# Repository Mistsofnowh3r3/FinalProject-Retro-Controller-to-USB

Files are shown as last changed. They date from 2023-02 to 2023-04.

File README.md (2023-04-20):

# Retro  Nintendo Controller Adapter

> Arduino code, ccAdapterRemapper Solution, stl's and sldprt's for a case, and design and usage documentation

## Dependencies
- https://github.com/MHeironimus/ArduinoJoystickLibrary
- https://github.com/SukkoPera/N64PadForArduino
- https://github.com/arduino-libraries/Keyboard
- https://www.arduino.cc/en/software

## Stuff
-- Params.cs is a modification of the PARAMS code from https://github.com/redscientistlabs/RTCV

-- Overall visual design of ccAdapterRemapper is inspired by RTCV as well.

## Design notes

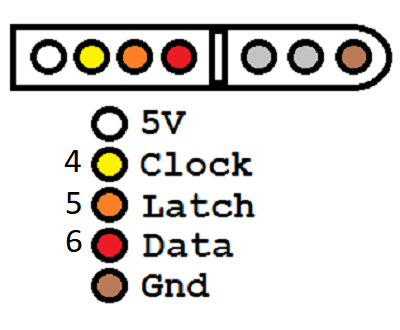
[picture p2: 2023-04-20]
Assets/Documentation/PINOUTS/SNES.png

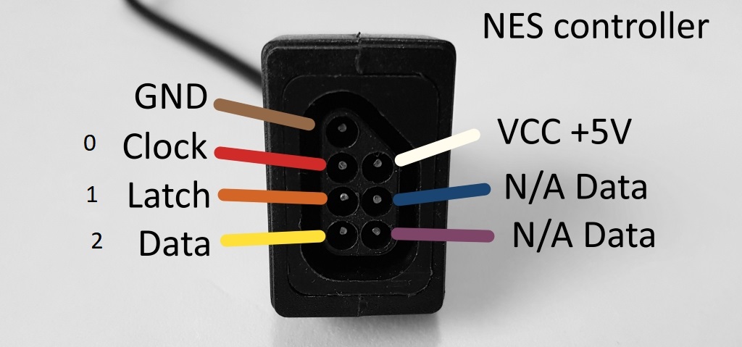
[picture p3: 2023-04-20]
Assets/Documentation/PINOUTS/NES.jpg

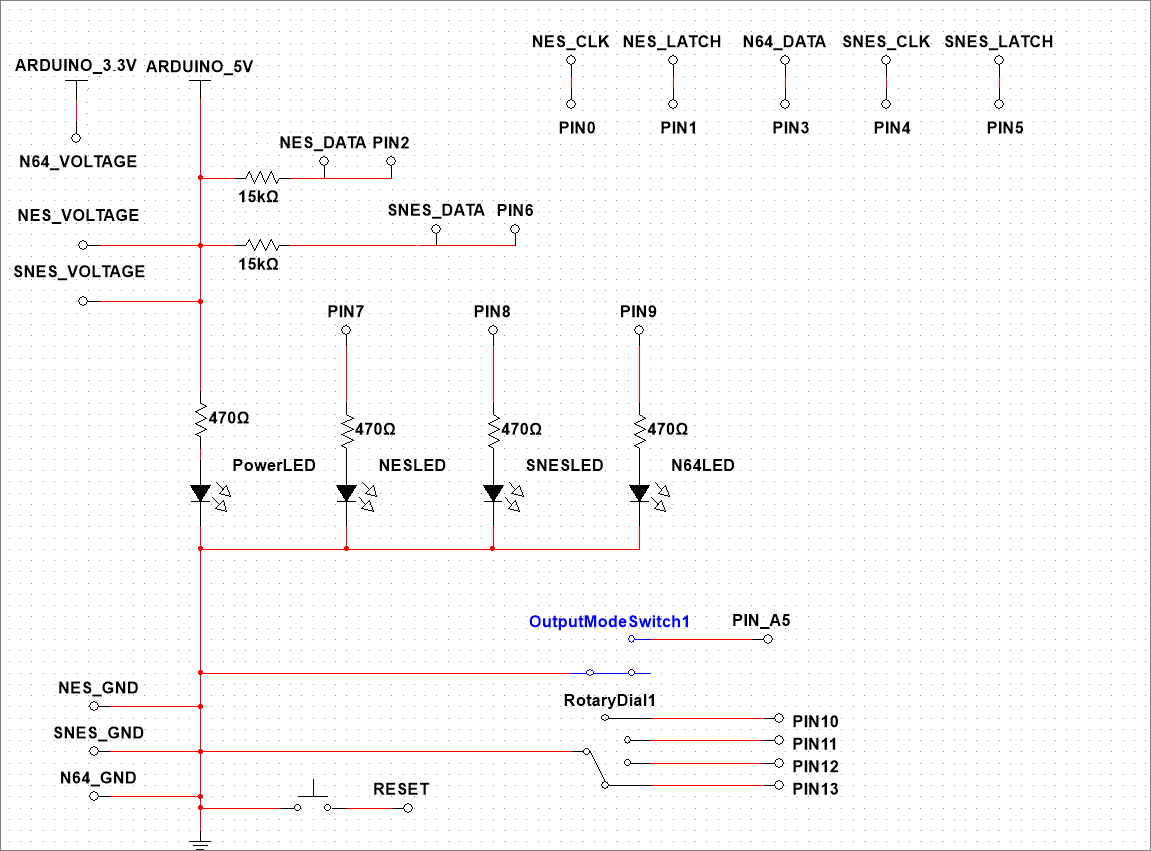
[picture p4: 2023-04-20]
Assets/Documentation/Circuit.png

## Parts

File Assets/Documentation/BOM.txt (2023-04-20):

4 LEDs
4 470 ohm or similar resistors for those LEDs
1 NES controller port
1 SNES controller port
1 N64 controller port
1 PBNO
1 SPDT switch
4 Position rotary dial
2 15k or similar pullup Resistors
1 Arduino Leonardo
1 Micro USB cable
Casing and wiring.

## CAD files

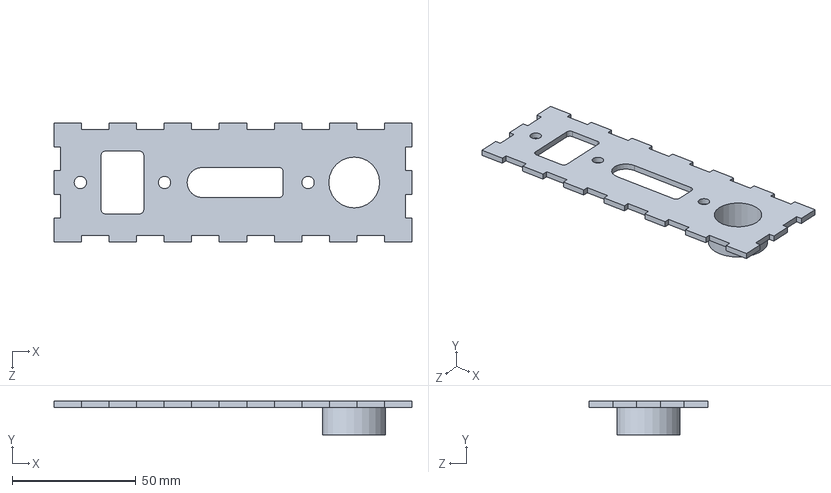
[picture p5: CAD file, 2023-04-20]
Assets/Case Model Files/Case Portside.SLDPRT
144.8 x 13.6 x 48.0 mm

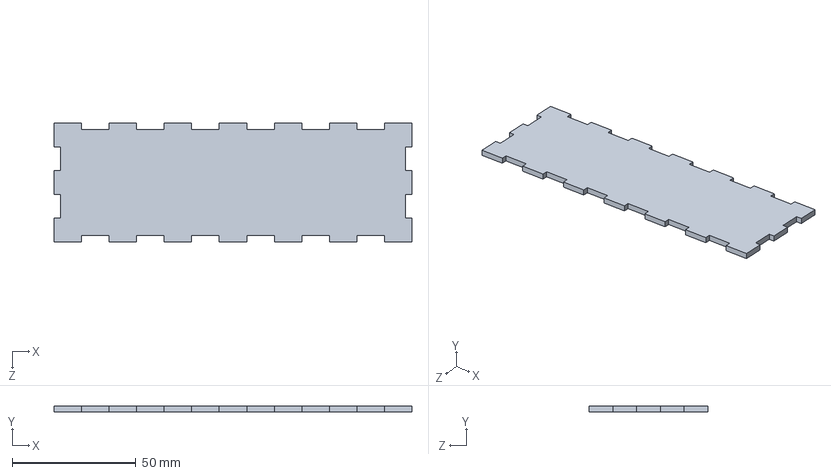
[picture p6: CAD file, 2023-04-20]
Assets/Case Model Files/Case Back Side.SLDPRT
144.8 x 2.54 x 48.0 mm

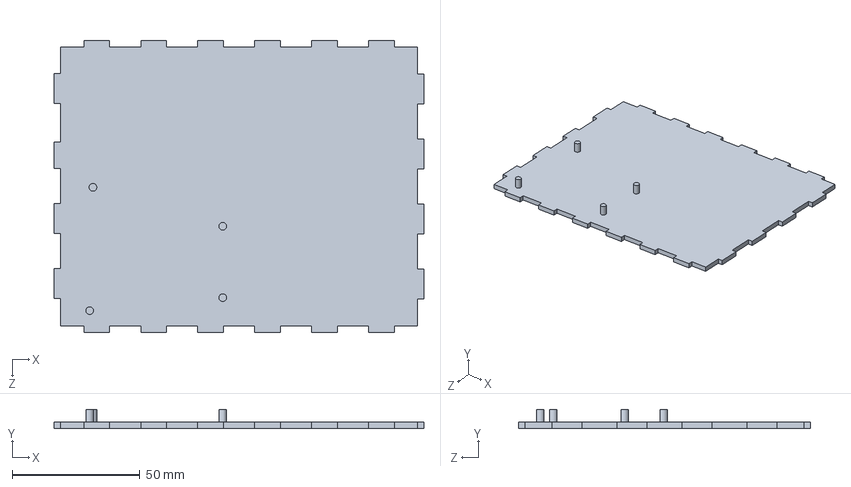
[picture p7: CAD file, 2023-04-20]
Assets/Case Model Files/Case Bottom.SLDPRT
144.8 x 7.62 x 114.3 mm

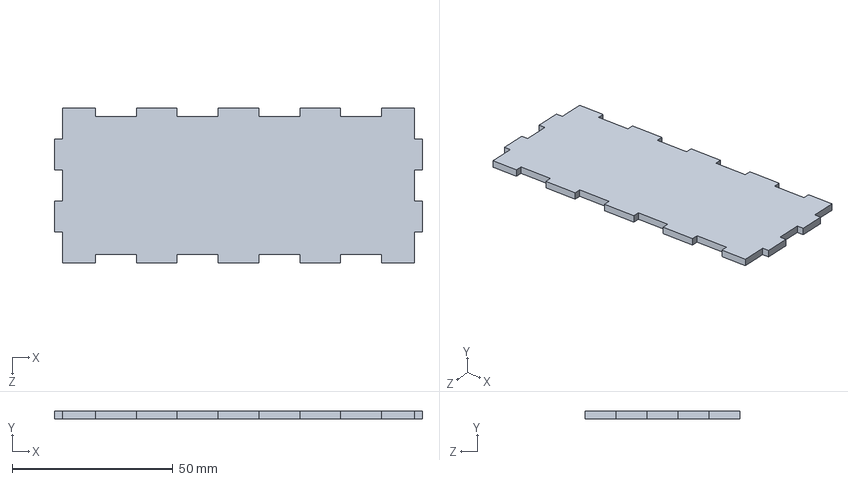
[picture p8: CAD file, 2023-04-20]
Assets/Case Model Files/Case Side.SLDPRT
114.3 x 2.54 x 48.0 mm

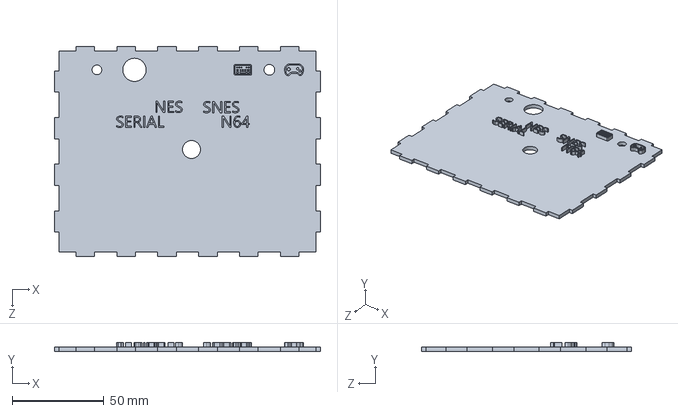
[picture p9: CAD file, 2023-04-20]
Assets/Case Model Files/Case Top.SLDPRT
144.8 x 5.08 x 114.3 mm

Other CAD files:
Assets/Case Model Files/Case Side Hole.SLDPRT
Assets/Case Model Files/Case Back Side.STL
Assets/Case Model Files/Case Bottom.STL
Assets/Case Model Files/Case Portside.STL
Assets/Case Model Files/Case Side Hole.STL
Assets/Case Model Files/Case Side.STL
Assets/Case Model Files/Case Top.STL

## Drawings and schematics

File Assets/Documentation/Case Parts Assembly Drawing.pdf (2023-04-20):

1

B B

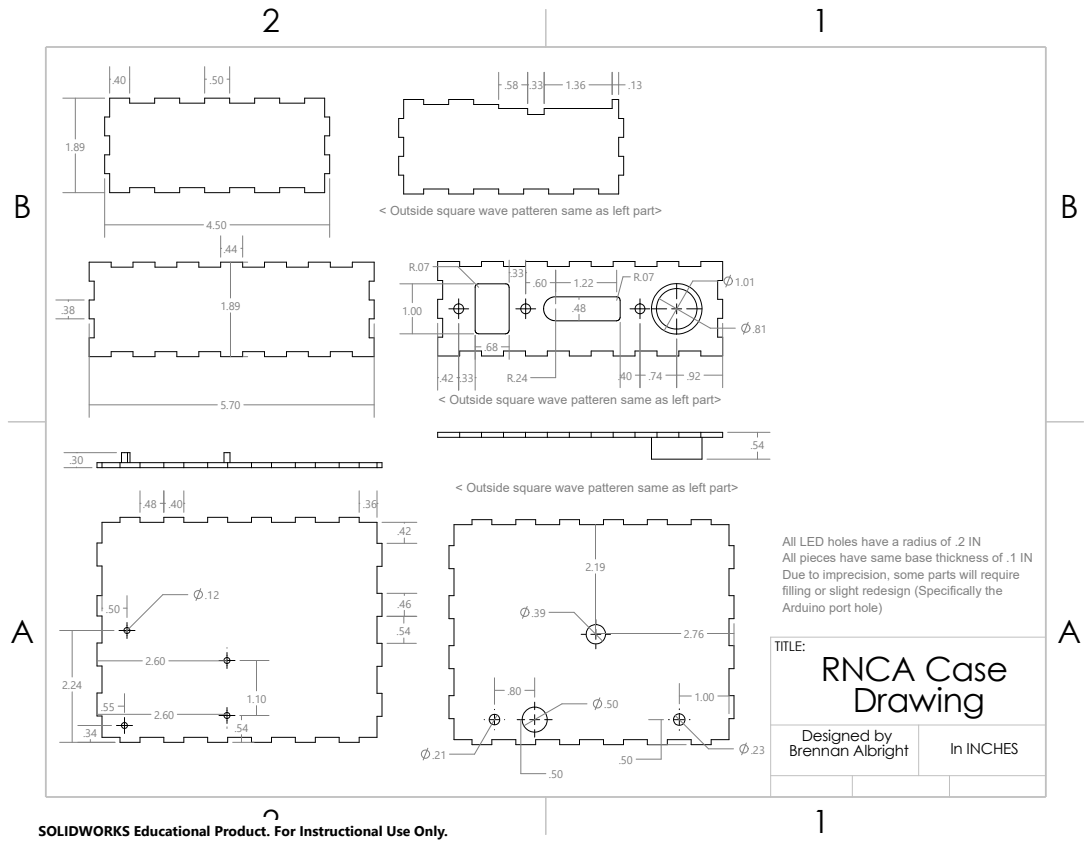
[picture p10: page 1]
TITLE:; Brennan Albright; Designed by; In INCHES

< Outside square wave patteren same as left part>

All LED holes have a radius of .2 IN
All pieces have same base thickness of .1 IN
Due to imprecision, some parts will require
filling or slight redesign (Specifically the
Arduino port hole)
RNCA Case
Drawing

SOLIDWORKS Educational Product. For Instructional Use Only.

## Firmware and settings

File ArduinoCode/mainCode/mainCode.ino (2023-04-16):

#include <N64Pad.h> // https://github.com/SukkoPera/N64PadForArduino
#include <Joystick.h> // https://github.com/MHeironimus/ArduinoJoystickLibrary
#include <Keyboard.h> // https://github.com/arduino-libraries/Keyboard
#include <EEPROM.h> // From Arduino IDE
#include <stdio.h> // From Arduino IDE

#pragma region // EEPROM MEMORY MAP
//0 NES A
//1 NES B
//2 NES SELECT
//3 NES START
//4 NES UP
//5 NES DOWN
//6 NES LEFT
//7 NES RIGHT
//8 SNES B
//9 SNES Y
//10 SNES UP
//11 SNES DOWN
//12 SNES LEFT
//13 SNES RIGHT
//14 SNES A 
//15 SNES X
//16 SNES L
//17 SNES R
//18 N64 //A     
//19 N64 //B
//20 N64 //Z
//21 N64 //START
//22 N64 //D UP
//23 N64 //D DOWN
//24 N64 //D LEFT
//25 N64 //D RIGHT
//26 N64 //C DOWN
//27 N64 //C LEFT
//28 N64 //L
//29 N64 //R
//30 N64 //C UP
//31 N64 //C RIGHT
//32 N64 //A UP
//33 N64 //A DOWN
//34 N64 //A LEFT
//35 N64 //A RIGHT
#pragma endregion

#pragma region // Variables

// Globals //

String serialNow = ""; // Holds the current text in the serial line

int working_NES_btns[] = { // Holds the current keyboard key mappings
    'z',            //A
    'x',            //B
    KEY_RETURN,     //SELECT
    32,             //START
    KEY_UP_ARROW,   //UP   
    KEY_DOWN_ARROW, //DOWN
    KEY_LEFT_ARROW, //LEFT
    KEY_RIGHT_ARROW,//RIGHT
};
int held_NES_btns[8]; // Holds the current held keyboard keys

int working_SNES_btns[] = { // Holds the current keyboard key mappings
    'z',            //B
    'x',            //Y
    KEY_RETURN,     //SELECT
    32,             //START
    KEY_UP_ARROW,   //UP   
    KEY_DOWN_ARROW, //DOWN
    KEY_LEFT_ARROW, //LEFT
    KEY_RIGHT_ARROW,//RIGHT
    'a',            //A
    's',            //X
    'q',            //L
    'w',            //R
};
int held_SNES_btns[12]; // Holds the current held keyboard keys

int working_N64_btns[] = { // Holds the current keyboard key mappings
    'z',            //A     
    'x',            //B
    KEY_RETURN,     //Z
    32,             //START
    KEY_UP_ARROW,   //D UP
    KEY_DOWN_ARROW, //D DOWN
    KEY_LEFT_ARROW, //D LEFT
    KEY_RIGHT_ARROW,//D RIGHT
    'k',            //C DOWN
    'j',            //C LEFT
    'q',            //L
    'e',            //R
    'i',            //C UP
    'l',            //C RIGHT
    'w',            //A UP
    's',            //A DOWN
    'a',            //A LEFT
    'd',            //A RIGHT
};
int held_N64_btns[18]; // Holds the current held keyboard keys

int controllerbutton_values[] = {0, 1, 2, 3, 4, 5, 6, 7, 8, 9, 10, 11}; // Array of the controller buttons
int n64KeyJoystickDeadZone = 20; // Deadzone for converting N64 joystick to keyboard key press

// Used for making sure that the DPAD functions correctly.
int holdCheckUpDown = 5;
int holdCheckLeftRight = 5;
int holdCheckUpDownN64Joy = 5;
int holdCheckLeftRightN64Joy = 5;

//various mode related things
// 0 serial, 1 NES, 2 SNES, 3 N64
int modeSelect = 0;
int modeSelectLast = 4;

// State of controller connections
bool nesControllerConnected = false;
bool nesControllerConnectedLast = false; 
bool snesControllerConnected = false; 
bool snesControllerConnectedLast = false; 
bool n64ControllerConnected = false;

// Controller/keyboard output select 
//  0 = Controller 1 = Keyboard 
bool outputMode = 0;
bool outputModelast = 0;

// Keeping track of when to read mappings from the arrays
bool mappingChanged = 0;

// Constants //

// This stuff was in the N64 pad example and was mostly undocumented. I've left it unedited because it just works.
// {
const byte ANALOG_DEAD_ZONE = 20U;
const int8_t ANALOG_MIN_VALUE = -80;
const int8_t ANALOG_MAX_VALUE = 80;
const int8_t ANALOG_IDLE_VALUE = 0;

N64Pad pad;

//sets up the joystick
Joystick_ usbStick (
	JOYSTICK_DEFAULT_REPORT_ID,
	JOYSTICK_TYPE_JOYSTICK,
	12,			// buttonCount
	0,			// hatSwitchCount (0-2)
	true,		// includeXAxis
	true,		// includeYAxis
	false,		// includeZAxis
	true,		// includeRxAxis
	true,		// includeRyAxis
	false,		// includeRzAxis
	false,		// includeRudder
	false,		// includeThrottle
	false,		// includeAccelerator
	false,		// includeBrake
	false		// includeSteering
);
#define deadify(var, thres) (abs (var) > thres ? (var) : 0)

//}


// Controller I/O Pins
const int pulsePinNes = 0; 
const int latchPinNes = 1; 
const int dataPinNes = 2; 
// N64 data pin is 3, defined in n64pad code
const int pulsePinSnes = 4; 
const int latchPinSnes = 5; 
const int dataPinSnes = 6; 

// LED Indicator Pins
const int nesIndicateLed = 7;
const int snesIndicateLed = 8;
const int n64IndicateLed = 9;

// Rotary dial pins
// SERIAL | NES | SNES | N64
const int serialDial = 10; 
const int nesDial = 11; 
const int snesDial = 12; 
const int n64Dial = 13; 

// Keyboard or Controller mode switch pin
const int outModeSwitch = PIN_A5; 

#pragma endregion


// Handles the Arduinos actions in serial mode.
void serialActions() {
    
    String parts[4]; // Create an array to hold 4 parts
    memset(parts, 0, sizeof(parts));  // Clear the parts array
    serialNow = Serial.readStringUntil('!');  // Read the command

    int partIndex = 0; // Initialize the array index
    for (int i = 0; i < serialNow.length(); i++) {
        char c = serialNow.charAt(i); // Get the character at i in serialNow 
        if (c == ',') partIndex++;  // If the character is a comma, move to the next substring in parts
        else parts[partIndex] += c; // Else, add the character to the current substring in parts
    }

    // POKE command, writes to a location in EEPROM
    // PO, ADR, VAL, CONSOLE !
    if (parts[0] == "PO") { 
        int adr = parts[1].toInt();
        int val = parts[2].toInt();

        if(parts[3] == "SNES") {
            adr += 8; // Add 8 to the address if SNES, makes sure we are at the SNES mapping memory address
        }
        else if(parts[3] == "N64") {
            adr += 18; // Add 18 to the address if N64, makes sure we are at the N64 mapping memory address
        }
        EEPROM.write(adr,val); // Write the value given to the address given
        mappingChanged = 1; // Let us know a mapping has changed
    }

    // PEEK command, reads the value at a location in EEPROM
    // PO, ADR, VAL, CONSOLE !
    if (parts[0] == "PE") { 
        int adr = parts[1].toInt();
        int val = EEPROM.read(adr);

        // Write the value at the address to serial
        Serial.write("PEEK @");
        Serial.println(adr);
        Serial.write(": ");
        Serial.println(val);
    }
    
}

// Reads from EEPROM to load the stored keyboard mappings
void loadKeyboardArrays() {
    for (int v = 0; v < 36; v++) {
        if ( v < 8) {
            if (EEPROM.read(v) != 0xff) { // Load a value in as long as it is not 0xFF (Supposedly the default from stock value) 
                working_NES_btns[v] = EEPROM.read(v);
            }    
        }
        if ( v > 7 && v < 18) {
            if (EEPROM.read(v) != 0xff) { // Load a value in as long as it is not 0xFF (Supposedly the default from stock value) 
                working_SNES_btns[v - 8] = EEPROM.read(v);
            }   
        }
        if ( v > 17) {
            if (EEPROM.read(v) != 0xff) { // Load a value in as long as it is not 0xFF (Supposedly the default from stock value) 
                working_N64_btns[v - 18] = EEPROM.read(v);
            } 
        }
    }
}

// Button press handling for NES and SNES controllers
void checkButton(int button_index) {
      
    if (button_index > 11) return; // If we have passed all the buttons just return

    if (outputMode == 1) { // If in keyboard mode
        // If in nesMode and button index < 8 then according to the inversion of the state of dataPinNes press or release a button
        // Does checks to make sure that you can map the same keyboard key to multiple controller buttons, and have it act as expected
        if ((modeSelect == 1) && button_index < 8) {     
            if(!digitalRead(dataPinNes)) { 
                Keyboard.press(tolower(working_NES_btns[button_index])); // tolower ensures the lowercase version of the key is pressed
                held_NES_btns[button_index] = working_NES_btns[button_index]; // Add the button to the held array
            }
            else {
                for(int op; op < 8; op++ ) { // Check if the button is currently in the held array
                    if (op == button_index ){ // Do not check for the current key being checked
                        continue; 
                    }
                    if (held_NES_btns[op] == working_NES_btns[button_index]) { // If the key is in the held array
                        held_NES_btns[button_index] = 0; // Remove it from the held array
                        return; // But return so the key does not get released
                    }
                }
                // Finally, if the key is not on the held array.
                Keyboard.release(tolower(working_NES_btns[button_index])); // Release it
                held_NES_btns[button_index] = 0; // Then remove it from the held array   
            }
            return;
        }
        // If in snesMode then according to the inversion of the state of dataPinSnes press or release a button
        // Does checks to make sure that you can map the same keyboard key to multiple controller buttons, and have it act as expected
        if ((modeSelect == 2)) {    
            if(!digitalRead(dataPinSnes)) { 
                Keyboard.press(tolower(working_SNES_btns[button_index])); // tolower ensures the lowercase version of the key is pressed
                held_SNES_btns[button_index] = working_SNES_btns[button_index]; // Add the button to the held array
            }
            else {
                for(int op; op < 12; op++ ) { // Check if the button is currently in the held array
                    if (op == button_index ){ // Do not check for the current key being checked
                        continue;
                    }
                    if (held_SNES_btns[op] == working_SNES_btns[button_index]) { // If the key is in the held array
                        held_SNES_btns[button_index] = 0; // Remove it from the held array
                        return; // But return so the key does not get released
                    }
                }
                // Finally, if the key is not on the held array.
                Keyboard.release(tolower(working_SNES_btns[button_index])); // Release it
                held_SNES_btns[button_index] = 0; // Then remove it from the held array
            }
        }
        return;
    }
    
    if (outputMode == 0) { // If in controller mode
        if ((modeSelect == 1) && button_index < 8) { // If in NES mode and not past the 8th button
            if (button_index > 3) { // Area of the Dpad buttons
                if ((button_index == 4) && (digitalRead(dataPinNes) == HIGH)) { // Try to stop holding up
                    if (holdCheckUpDown == 1) { // Check if we are holding up
                        usbStick.setYAxis(ANALOG_IDLE_VALUE); // Release up
                        holdCheckUpDown = 0; // Let us know up is no longer held
                    } 
                }
                if ((button_index == 5) && (digitalRead(dataPinNes) == HIGH)) { // Try to stop holding down
                    if (holdCheckUpDown == 2) { // Check if we are holding down
                        usbStick.setYAxis(ANALOG_IDLE_VALUE); // Release down
                        holdCheckUpDown = 0; // Let us know down is no longer held
                    } 
                }
                if ((button_index == 4) && (digitalRead(dataPinNes) == LOW)) { // Try to press up
                    usbStick.setYAxis(ANALOG_MIN_VALUE); // Press up
                    holdCheckUpDown = 1; // We are holding up
                }
                if ((button_index == 5) && (digitalRead(dataPinNes) == LOW)) { // Try to press down
                    usbStick.setYAxis(ANALOG_MAX_VALUE); // Press down
                    holdCheckUpDown = 2; // We are holding down
                }


                if ((button_index == 6) && (digitalRead(dataPinNes) == HIGH)) { // Try to stop holding left
                    if (holdCheckLeftRight == 1) { // Check if we are holding left
                        usbStick.setXAxis(ANALOG_IDLE_VALUE); // Release left
                        holdCheckLeftRight = 0; // Let us know left is no longer held
                    } 
                }
                if ((button_index == 7) && (digitalRead(dataPinNes) == HIGH)) { // Try to stop holding right
                    if (holdCheckLeftRight == 2) { // Check if we are holding right
                        usbStick.setXAxis(ANALOG_IDLE_VALUE); // Release
                        holdCheckLeftRight = 0; // Let us know right is no longer held
                    } 
                }
                if ((button_index == 6) && (digitalRead(dataPinNes) == LOW)) { // Try to press left
                    usbStick.setXAxis(ANALOG_MIN_VALUE); // Press left
                    holdCheckLeftRight = 1; // We are holding left
                }
                if ((button_index == 7) && (digitalRead(dataPinNes) == LOW)) { // Try to press right
                    usbStick.setXAxis(ANALOG_MAX_VALUE); // Press right
                    holdCheckLeftRight = 2; // We are holding right
                }
                usbStick.sendState(); // Send the controller state
                return; // Return to not mess stuff up
            }
            // Press the button at the index according to the datapin read
            usbStick.setButton(controllerbutton_values[button_index], !digitalRead(dataPinNes)); 
            usbStick.sendState();
            return;
        }

        if (modeSelect == 2) { // If in SNES mode
            if (button_index > 3 && button_index < 8) { // Area of the Dpad buttons
                if ((button_index == 4) && (digitalRead(dataPinSnes) == HIGH)) { // Try to stop holding up
                    if (holdCheckUpDown == 1) { // Check if we are holding up
                        usbStick.setYAxis(ANALOG_IDLE_VALUE); // Release up
                        holdCheckUpDown = 0; // Let us know up is no longer held
                    } 
                }
                if ((button_index == 5) && (digitalRead(dataPinSnes) == HIGH)) { // Try to stop holding down
                    if (holdCheckUpDown == 2) { // Check if we are holding down
                        usbStick.setYAxis(ANALOG_IDLE_VALUE); // Release down
                        holdCheckUpDown = 0; // Let us know down is no longer held
                    } 
                }
                if ((button_index == 4) && (digitalRead(dataPinSnes) == LOW)) { // Try to press up
                    usbStick.setYAxis(ANALOG_MIN_VALUE); // Press up
                    holdCheckUpDown = 1; // We are holding up
                }
                if ((button_index == 5) && (digitalRead(dataPinSnes) == LOW)) { // Try to press down
                    usbStick.setYAxis(ANALOG_MAX_VALUE); // Press down
                    holdCheckUpDown = 2; // We are holding down
                }

                if ((button_index == 6) && (digitalRead(dataPinSnes) == HIGH)) { // Try to stop holding left
                    if (holdCheckLeftRight == 1) { // Check if we are holding left
                        usbStick.setXAxis(ANALOG_IDLE_VALUE); // Release left
                        holdCheckLeftRight = 0; // Let us know left is no longer held
                    } 
                }
                if ((button_index == 7) && (digitalRead(dataPinSnes) == HIGH)) { // Try to stop holding right
                    if (holdCheckLeftRight == 2) { // Check if we are holding right
                        usbStick.setXAxis(ANALOG_IDLE_VALUE); // Release right
                        holdCheckLeftRight = 0; // Let us know right is no longer held
                    }  
                }
                if ((button_index == 6) && (digitalRead(dataPinSnes) == LOW)) { // Try to press left
                    usbStick.setXAxis(ANALOG_MIN_VALUE); // Press left
                    holdCheckLeftRight = 1; // We are holding left
                }
                if ((button_index == 7) && (digitalRead(dataPinSnes) == LOW)) { // Try to press right
                    usbStick.setXAxis(ANALOG_MAX_VALUE); // Press right
                    holdCheckLeftRight = 2; // We are holding right
                }
                usbStick.sendState(); // Send the controller state
                return; // Return to not mess stuff up
            }
            // Press the button at the index according to the datapin read
            usbStick.setButton(controllerbutton_values[button_index], !digitalRead(dataPinSnes)); 
            usbStick.sendState(); 
        }
    }
}

// Releases all buttons and keyboard keys
void clearAllButtons() {
    // Go through all held buttons arrays and initialize them to zero
    for (int v = 0; v < 36; v++) {
        if ( v < 8) held_NES_btns[v] = 0;
        if ( v > 7 && v < 18) held_SNES_btns[v - 8] = 0;
        if ( v > 17) held_N64_btns[v - 18] = 0;
    }
    usbStick.setYAxis(ANALOG_IDLE_VALUE); // Clear the Dpad
    usbStick.setXAxis(ANALOG_IDLE_VALUE); // Clear the Dpad
    usbStick.setRyAxis(ANALOG_IDLE_VALUE); // Clear the joystick
    usbStick.setRxAxis(ANALOG_IDLE_VALUE); // Clear the joystick
    for(int u = 0; u < 12; u++) usbStick.setButton(controllerbutton_values[u], 0); // Clear the buttons
    usbStick.sendState();
    Keyboard.releaseAll(); // Release all keys
}

// Contructs the timing for supplying pulse and clock to the NES controller, and reads the values at it's dataPin at the right time
void nes() {
    nesControllerConnectedLast = nesControllerConnected; // Store the last known state of of the controllers connection

    // NES latch signal generation
    digitalWrite(latchPinNes, HIGH); // Write high to the latchPin
    if (nesControllerConnected && (modeSelect == 1)) checkButton(0); // Check for A here
    delayMicroseconds(12); // Keep latchPin high for 12 ms

    digitalWrite(latchPinNes, LOW); // Write low to the latchPin
    delayMicroseconds(6); // Wait 6 ms
    
    // NES pulse signal generation
    for (int j = 1; j < 8; j++) // Create 7 pulses on the pulse pin
    {
        digitalWrite(pulsePinNes, HIGH); // Write high to the pulsePin
        if (nesControllerConnected && (modeSelect == 1)) checkButton(j); // Check for all other buttons
        delayMicroseconds(6); // Keep pulsePin high for 6 ms

        digitalWrite(pulsePinNes, LOW); // Write low to the pulsePin
        delayMicroseconds(6); // Keep pulsePin low for 6 ms
    }

    for (int t = 7; t < 16; t++) { // Extra pulses for checking if an NES controller is connected
        digitalWrite(pulsePinNes, HIGH); // Write high to the pulsePin
        digitalRead(dataPinNes) ? nesControllerConnected = false : nesControllerConnected = true; // If read low here a controller is connected
        digitalWrite(nesIndicateLed, nesControllerConnected ? HIGH : LOW); // Turn the LED on or off

        delayMicroseconds(6); // Keep pulsePin high for 6 ms

        digitalWrite(pulsePinNes, LOW); // Write low to the pulsePin
        delayMicroseconds(6); // Keep pulsePin low for 6 ms
    }
    
    // If a NES controller is not connected, and the connection has changed 
    if(!nesControllerConnected && (nesControllerConnected != nesControllerConnectedLast)) { 
        clearAllButtons(); 
    }
}
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
void loop() {  
  
    // Check the output mode switch
    outputMode = digitalRead(outModeSwitch);
    if(outputMode != outputModelast) {
        clearAllButtons(); // If the output mode switch changed state, clear all buttons
    }
    outputModelast = outputMode;

    // Check the controller selection dial state
    checkDial();
    if( modeSelectLast != modeSelect) {
        clearAllButtons(); // If the mode dial changed state, clear all buttons
    }
    modeSelectLast = modeSelect;


    // Main stuff
    if (modeSelect == 0) {
        serialActions(); // Only call serial actions if in serial mode
        if (mappingChanged) { // Check if any of the mappings where changed
            loadKeyboardArrays(); // If they were, reload the arrays
            mappingChanged = 0;
        }
    }
    else {
        nes();
        snes();
        n64();
        digitalWrite(n64IndicateLed, n64ControllerConnected);
    }         
    
}

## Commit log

2023-01-31 Full function NES minus some timing issue
    [mainCode.ino]
2023-02-01 Timing actually based on micro seconds now. Doesn't work anymore though
    [mainCode.ino]
2023-02-11 Added N64PadForArduino, axed Xinput stuff
    N64 seems to complicated for me to do in a way that will work. Due to speed requirements it would likely necessitate partial assembly, which I do not want to do myself. So, I am instead using this li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
2023-02-13 Remove SNES mouse + Switch Stuff + Cleanup + Documenting
2023-02-15 Work on button inputs for NES and SNES
2023-02-20 ALL WORKING just before switching to pullup
2023-02-20 NES and SNES controller full integration.
    Knows if they are, or are not connected.
    No mystery inputs when they disconnect.
    Can do indicator LEDs for both.
    It's just that easy
2023-03-13 Bug fixes + SNES Remap
    [mainCode.ino]
2023-03-14 Clean up and bug fixes
    [mainCode.ino]
2023-03-22 MULTIKEY BUG IS FIXED (for nes)
    [mainCode.ino]
2023-03-22 Should be fixed for SNES too
    [mainCode.ino]
2023-03-23 Fixed for all controllers!!!
    [mainCode.ino]
2023-03-28 Arduino side code is cleaaann
2023-04-20 Added Documentation and model files
    [Case Back Side.SLDPRT, Case Back Side.STL, Case Bottom.SLDPRT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]
